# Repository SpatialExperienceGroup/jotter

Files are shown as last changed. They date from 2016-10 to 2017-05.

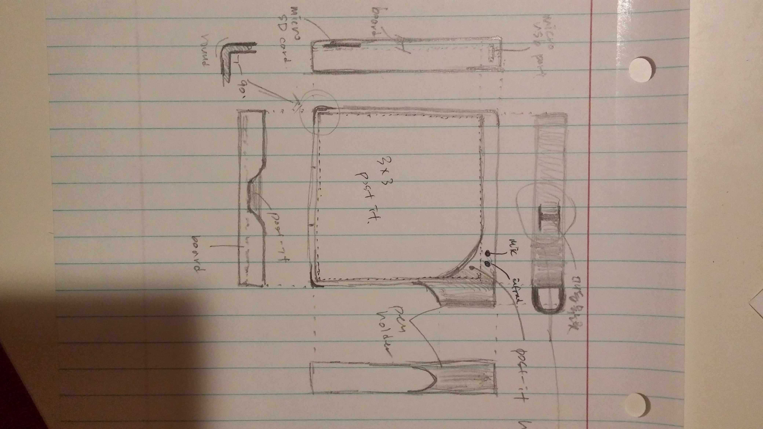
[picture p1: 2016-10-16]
References/20160215_013802_HDR.jpg

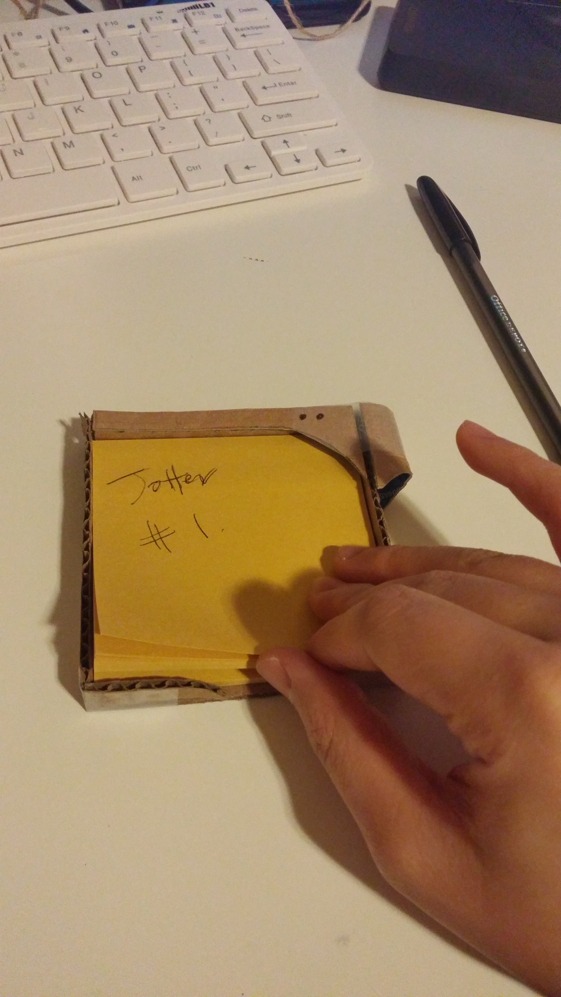
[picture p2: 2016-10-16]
References/20160215_014430_HDR.jpg

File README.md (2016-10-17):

# Jotter

## Requirements
- micro usb port for charging and for updating firmware
- 3.7V from a lipo battery
- lipo charging circuitry through a micro usb port
- bluetooth low energy beacon receiver and transmitter for positioning and ideally multilateration
- MCU to handle bluetooth beacon code
- accurate real time clock
- sd card for storing data; consider storing the unit id number on the sd card
- mems microphone on front for capturing talking of others
- mems microphone on the back for capturing talking of user
- MCU for DFT processing of the audio signals
- IrDA or similar for transmitting and receiving unique IDs to identify users facing users
- MCU to handing IrDA
- accelerometer to identify leaning and sitting
- pressure sensor to identify sitting and standing, usually these are only accurate to within 1 meter, which might not be good enough
- Wi-Fi capability for updating firmware, changing settings, and downloading data
- Any LEDs? charging, Wi-Fi transmission
- Any Buttons? Wi-Fi mode

---------------
## RTC
### DS3231*
- Arduino Library: Rtc by Makuna, Sodaq_DS3231

#### DS3231SN
- has temperature compensated crystal oscillator (may need this for cold temps)
- TCXO:Yes
- Alamrs:2
- $9.97@1, digi-key
- $6.59@100, digi-key
- $2.50@10, aliexpress

---------------
## Coin Cell Retainer/Holder
- Battery:CR2032
- Battery Diameter:20mm

### BU2032

#### BU2032-1-HD-G
- Type:through hole holder
- $0.83@1, digi-key
- $0.69@100, digi-key

#### BU2032SM-HD-G
- Type:surface mount holder
- $0.87@1, digi-key
- $0.76@100, digi-key

#### BK-912
- Type:surface mount retainer
- Notes:easy replacement
- $0.33@1, digi-key
- $0.29@100, digi-key

#### BK-913*
- Type:through hole retainer
- Notes:easy replacement
- $0.35@1, digi-key
- $0.30@100, digi-key

#### BK-888
- Type:through hole retainer
- blocks inner side
- easy replacement
- $0.39@1, digi-key
- $0.33@100, digi-key

---------------
## LDO
- Voltage 3.3V
- needed for running the esp8266 microprocessor and others
- ESP8266 typical
-- Modem-Sleep is 15mA with not much load
-- Wi-Fi Transmission could be up to 170mA, but it is unclear if this is an instantaneous load

### AMS1117-3.3**
- Package:SOT-223
- Current: 1100mA
- Input Voltage: Up to 6V
- Dropout Voltage: 1100mV@800mA
- $1.58@50, aliexpress

### SPX3819M5-L-3-3/TR**
- Package: SOT-23-5
- Current: 500mA
- Input Voltage: Up to 16V
- Dropout Voltage: 340mV@500mA
- $0.72@1, digi-key
- $0.49@100, digi-key

### MCP1700T-3302E/TT
- Package: SOT-23-3
- Current: 250mA
- Input Voltage: Up to 6V
- Dropout Voltage: 178mV@250mA
- $0.37@1, digi-key
- $0.28@100, digi-key

### TC1262-3.3VDBTR
- Package: SOT-223-3
- Current: 500mA
- Input Voltage: Up to 6V
- Dropout Voltage: 350mV@500mA
- $0.51@1, digi-key
- $0.39@100, digi-key

### MIC5528-3.3YMY-TR
- Package: 6-UFDFN (1.2x1.2)
- Current: 525mA
- Input Voltage: 2.5V to 5.5V
- $0.19@1, digi-key
- $0.14@100, digi-key

### NCP161AMX330TBG
- Package: 4-XDFN (1x1)
- Current: 450mA
- Input Voltage: 1.9V to 5.5V
- Dropout Voltage: 150mV@450mA
- $0.46@1, digi-key
- $0.22@100, digi-key

---------------
## LiPo Battery
- 3.7V

### 100mAh
- Weight: 3g
- Size: 11.5mm x 31 x 3.8mm / 0.45" x 1.2" x 0.15"
-   4mA@24hr
-  10mA@10hr
-  $5.95@1, Adafruit
-  $4.76@100, Adafruit

### 150mAh
- Weight: 4.65g
- Size: 19.75mm x 26.02mm x 3.8mm / 0.77" x 1.02" x 0.14"
-   6mA@24hr
-  15mA@10hr
-  $5.95@1, Adafruit
-  $4.76@100, Adafruit

### 350mAh
- Weight: 7.9g
- Size: 36mm x 20mm x 5.6mm / 1.4" x 0.8" x 0.22"
-  14mA@24hr
-  35mA@10hr
-  $6.95@1, Adafruit
-  $5.56@100, Adafruit

### 500mAh**
- Weight: 10.5g
- Size: 29mm x 36mm x 4.75mm / 1.15" x 1.4" x 0.19"
-- Little larger than a US Quarter
-  20mA@24hr
-  50mA@10hr
-  $7.95@1, Adafruit

### 1200mAh*
- Weight: 23g
- Size: 34mm x 62mm x 5mm / 1.3" x 2.4" x 0.2"
-  50mA@24hr
- 120mA@10hr
-  $9.95@1, Adafruit

### 2000mAh
- Weight: 34g
- Size: 60mm x 36mm x 7mm / 2.4" x 1.4" x 0.3"
-  83mA@24hr
- 200mA@10hr
- $12.50@1, Adafruit
- $10.00@100, Adafruit

### 2500mAh
- Weight: 52g
- Size: 2" x 2.55" x 0.30" (51mm x 65mm x 8mm)
- 104mA@24hr
- 250mA@10hr
- $14.95@1, Adafruit
- $11.96@100, Adafruit

---------------
## LiPo Charger

### MCP73831/2**
- Used by Adafruit
- Package: SOT-23-5
- Max Charge Current: 500mA
- Max Input Voltage: 6V
- $0.56@1, digi-key
- $0.42@100, digi-key

### MAX1555EZK+T
- Package: SOT-23-5
- Max Charge Current: 340mA
- Max Input Voltage: 7V
- $2.03@1, digi-key
- $1.34@100, digi-key

---------------
## MCU - Core

### ATSAMD11
- USB: Yes
- VCC: 1.62V - 3.63V
- Current Consumption Idle: 1.8mA
- Current Consumption While: 3mA
- Current Consumption CoreMark: 4mA
- Program Memory: 16KB
- CPU Frequency: 48MHz

#### ATSAMD11C
- SERCOM: 2

##### ATSAMD11C14A
- Package: 14-SOIC
- $2.32@1, digi-key
- $1.69@100, digi-key

#### ATSAMD11D
- SERCOM: 3

##### ATSAMD11D14A

###### ATSAMD11D14A-SSUT**
- Package: 20-SOIC
- $2.54@1, digi-key
- $1.85@100, digi-key

###### ATSAMD11D14A-MUT*
- Package: 24-QFN (4x4)
- $2.65@1, digi-key
- $1.93@100, digi-key

### ATSAMD21
- USB: Yes
- VCC: 1.62V - 3.63V
- Current Consumption Idle: 2.2mA
- Current Consumption While: 4mA
- Current Consumption CoreMark: 7mA
- Program Memory: 32/64/128/256KB
- CPU Frequency: 48MHz
- I2S: Yes

#### ATSAMD21E
- SERCOM:4
- ADC:10

##### ATSAMD21E18A
- Program Memory: 256KB

###### ATSAMD21E18A-MUT
- Package:32-VFQFN
- $5.30@1, digi-key
- $3.88@100, digi-key

###### ATSAMD21E15B-AUT
- Package:32-TQFP (7x7)
- $3.16@1, digi-key
- $2.32@100, digi-key

#### ATSAMD21G
- SERCOM:6
- ADC:14

#### ATSAMD21J
- SERCOM:6
- ADC:20

### LPGA
- Custom Reprogrammable Circuit Design

#### ICE40LP384-SG32
- Package: 32-QFN
- LABS/CLBs: 48
- Logic Elements: 384
- Dev Kit http://www.latticestore.com/searchresults/tabid/463/searchid/1/searchvalue/ice40hx1k-blink-evn/default.aspx
- $1.67@1, digi-key
- $1.38@100, digi-key

---------------
## MCU - IrDA, Bluetooth

### ATtiny85
- GCC Architecture: avr25
- Program Memory: 8KB
- TWI: 0
- SPI: 0
- USART: 0
- ADC: 4x10b

#### ATTINY85-20SU
- Package: 8-SOIC
- CPU Frequency: 20MHz
- $2.24@1, digi-key
- $1.63@100, digi-key

#### ATTINY85-20MUR
- Package: 20-QFN (4x4)
- CPU Frequency: 20MHz
- $2.08@1, digi-key
- $1.51@100, digi-key

### ATtiny841
- Program Memory: 8KB
- GCC Architecture: avr25
- CPU Frequency: 16MHz
- TWI: 1 Slave
- SPI: 1
- USART: 2

#### ATTINY841-SSUR**
- Package: 14-SOIC
- $2.11@1, digi-key
- $1.53@100, digi-key

#### ATTINY841-MUR*
- Package: 20-QFN (4x4)
- $2.16@1, digi-key
- $1.56@100, digi-key

#### ATTINY841-MMHR
- Package: 20-VQFN (3x3)
- $2.32@1, digi-key
- $1.68@100, digi-key

### ATtiny88
- Program Memory: 8KB
- GCC Architecture: avr25
- CPU Frequency: 12MHz
- TWI: 1
- SPI: 1
- USART: 0

#### ATTINY88-MU
- Package: 32-VQFN (5x5)
- $1.82@1, digi-key
- $1.32@100, digi-key

#### ATTINY88-AU
- Package: 32-TQFP (7x7)
- $1.96@1, digi-key
- $1.42@100, digi-key

### ATtiny40
- Program Memory: 4KB
- GCC Architecture: avrtiny10
- CPU Frequency: 12MHz
- TWI: 1 Slave
- SPI: 1
- USART: 0

#### ATTINY40-MMHR
- Package: 20-VQFN (3x3)
- $1.49@1, digi-key
- $1.09@100, digi-key

#### ATTINY40-XUR
- Package: 20-TSSOP
- $2.20@1, digi-key
- $1.60@100, digi-key

#### ATTINY40-SUR
- Package: 20-SOIC
- $2.14@1, digi-key
- $1.55@100, digi-key

### ATtiny828
- Program Memory: 8KB
- GCC Architecture: avr25
- CPU Frequency: 20MHz
- TWI: 1 Slave
- SPI: 1
- USART: 1

#### ATTINY828-AUR
- Package: 32-TQFP (7x7)
- $2.45@1, digi-key
- $1.78@100, digi-key

#### ATTINY828-MUR
- Package: 32-VQFN (5x5)
- $2.67@1, digi-key
- $1.94@100, digi-key

---------------
## MEMS Microphones
- I2S digital input type
- Sensitivity: http://www.analog.com/en/analog-dialogue/articles/understanding-microphone-sensitivity.html
-- In near-field applications, such as cell phones, where the microphone is close to the sound source, a microphone with higher sensitivity is more likely to reach the maximum acoustic input, clip, and cause distortion. On the other hand, a higher sensitivity may be desirable in far-field applications, such as conference phones and security cameras, where the sound is attenuated as the distance from the source to the microphone increases.
-- Normal Conversation at 1m is around 63dB SPL

### SPH0645LM4H-B*
- Port: Bottom
- Frequency Range: 20Hz to 20kHz
- Sensitivity: -26dB ±3dB @ 94dB SPL
- SNR: 65dB(A)
- Supply Volgage: 1.62V to 1.8V to 3.6V
- Supply Current: 0.6mA
- Precision: 18-bit (6 additional bits are zeros, making 24-bit total)
- $3.06@1, digi-key
- $2.29@1, mouser
- $1.90@100, digi-key
- $1.51@100, mouser

### ICS-43432
- Port: Bottom
- Frequency Range: 50Hz to 20kHz
- Sensitivity: -26dB ±1dB @ 94dB SPL
- SNR: 65dB(A)
- Supply Volgage: 1.62V to 1.8V to 3.6V
- Supply Current: 1.5mA
- Precision: 24-bit
- $3.18@1, digi-key
- $2.15@100, digi-key
- example circuit: https://www.tindie.com/products/onehorse/ics43432-i2s-digital-microphone/
- Library: https://github.com/nodae/teensy_i2s_experimental

### INMP441ACEZ-R7
- Port: Bottom
- Frequency Range: 60Hz to 15kHz
- Sensitivity: -26dB ±3dB @ 94dB SPL
- SNR: 61dB(A)
- Supply Volgage: 1.62V to 1.8V to 3.6V
- Supply Current: 1.6mA
- Precision: 24-bit
- $4.35@1, digi-key
- $3.14@100, digi-key

### SPU0414HR5H
- Output Type: Analog
- Port: Top
- Frequency Range: 100Hz to 10kHz
- Sensitivity: -22dB ±3dB @ 94dB SPL
- SNR: 59dB(A)
- Supply Volgage: 1.5V to 3.6V
- Supply Current: 0.22mA
- $2.01@1, digi-key
- $1.10@100, digi-key
- $1.87@1, mouser
- $1.03@100, mouser

### SPW2430HR5H-B
- Output Type: Analog
- Port: Top
- Frequency Range: 100Hz to 10kHz
- Sensitivity: -42dB ±3dB @ 94dB SPL (not good)
- SNR: 59dB(A)
- Supply Volgage: 1.5V to 3.6V
- Supply Current: 0.11mA
- $1.11@1, digi-key
- $0.60@100, digi-key
- $1.04@1, mouser
- $0.59@100, mouser

## MCU - DFT Audio Signal Processor
- Interface: I2S

### ESP8266*
- Wi-Fi:Yes
- Allows us to have a Wi-Fi interface for setting the time and other settings.
- VCC:3.3V
- Runs on 3.3V, so should have an LDO or similar to bring down the 5V supply.
- pin mapping: http://www.esp8266.com/wiki/doku.php?id=esp8266_gpio_pin_allocations
- Has I2S inputs for digital audio of Left and Right microphones
- Peak Current Consumption on Startup: 320mA (use 470uF SMD)
- Current Consumption Idle: 15mA
- Current Consumption Wi-Fi Receive: 70mA
- Current Consumption Wi-Fi Transmit: <170mA
- I2S Forum: http://www.esp8266.com/viewtopic.php?f=13&t=7404
- I2S Example Code: https://github.com/cnlohr/esp8266duplexi2s
- DFT Example Code: https://github.com/cnlohr/channel3

### ATSAMD21

#### ATSAMD21E18A-MUT
- Package:32-VFQFN
- $5.30@1, digi-key
- $3.88@100, digi-key

#### ATSAMD21E15B-AUT
- Package:32-TQFP (7x7)
- $3.16@1, digi-key
- $2.32@100, digi-key

---------------
## IrDA Transciever
- http://www.societyofrobots.com/electronics_irda_tutorial.shtml
- Modulation Frequency: 38KHz
- most single packages are expensive, so we split into two parts
- may need to offload processing to small chip like Attiny85

### IrDA Sensor Pair

### IrDA Processor
- Encoder/Decoder

#### ATtiny MCU

#### MCP2155

#### MCP2122

### IrDA Receiver

#### VS1838B

#### TSOP38238

#### TSOP4038

#### TSOP4838

#### HS0038B

#### TSOP58238

#### TSOP6238TR

#### TSMP77000TT
- Distance: 5m
- Voltage Supply: 2.5V to 5.5V
- $1.66@1, digi-key
- $1.21@100, digi-key

### IrDA Transmitter
- Can be controlled with a 555 timer or an MCU

#### ATtiny MCU

#### NE555
- Supply Voltage: Typically 5V operation
- Max Frequency: 1MHz

#### TLC555
- Supply Voltage: 2V-15V
- Temperature Range: 0C to +70C
- Package: 8-SOIC
- Max Frequency: 2.1MHz
- $0.72@1, digi-key
- $0.48@100, digi-key

#### ICM7555
- Supply Voltage: 2V-18V
- Drop in replacement for NE555
- Max Frequency: 1MHz

##### ICM7555CBAZ
- Package: 8-SOIC
- Temperature Range: 0C to +70C
- $0.73@1, digi-key
- $0.50@100, digi-key

##### ICM7555IBAZ
- Package: 8-SOIC
- Temperature Range: -25C to +85C
- $0.73@1, digi-key
- $0.50@100, digi-key

---------------
## IMU
- need to detect sitting vs standing
- may include accelerometer, gyro, barometer, and perhaps magnetometer; why not

### MPU9250
- DoF:9

---------------
## Environmental Sensor

### BMP280

---------------
## Bluetooth Module for Beacon

### nRF24L01+*
- Chipset: nRF24L01
- FCC Certified: No

### MDBT40P**
- Chipset:nrf51822
- FCC Certified: Yes, SH6MDBT40

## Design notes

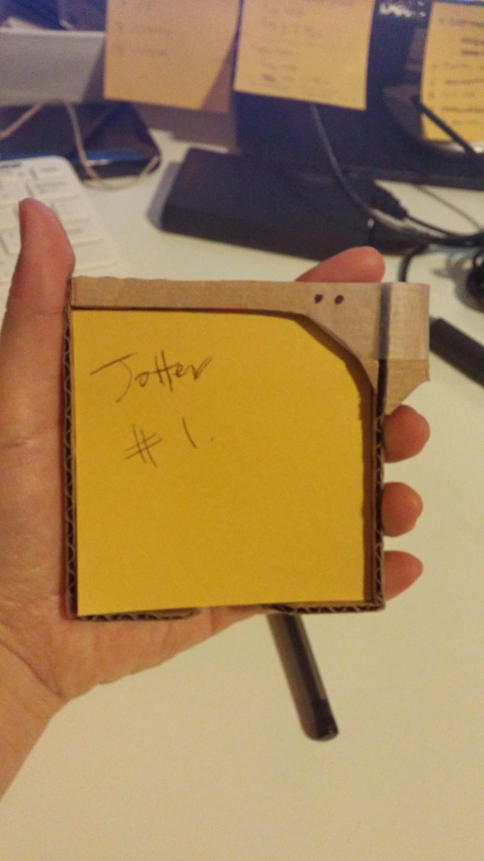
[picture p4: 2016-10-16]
References/20160215_014537_HDR.jpg

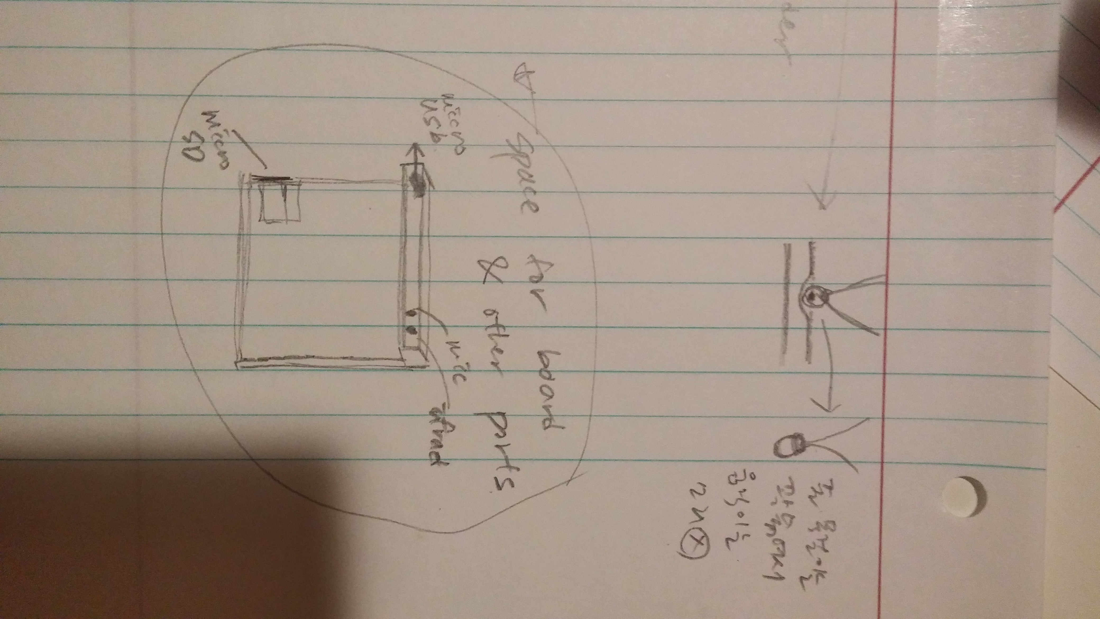
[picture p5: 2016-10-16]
References/20160215_013808_HDR.jpg

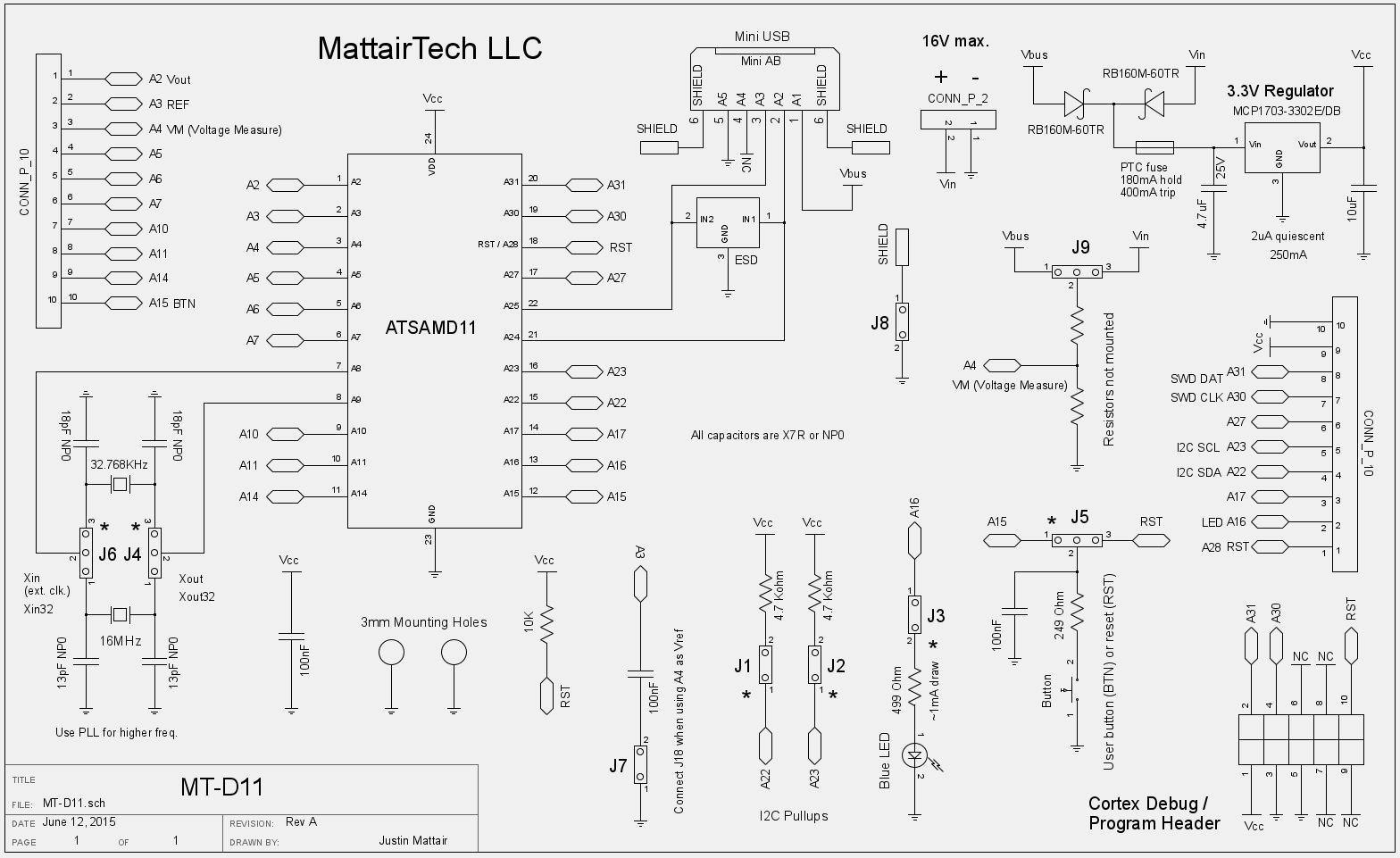
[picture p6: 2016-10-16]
References/research/mt-d11.png

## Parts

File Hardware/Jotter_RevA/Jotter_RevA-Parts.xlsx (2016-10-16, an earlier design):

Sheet: Jotter_Rev1
Section | part | specs | footprint | qty | unit cost | unit 100 | supplier | qty10 | part number | hyperlink | subtotal | subtotal10 | subtotal100 | notes
https://learn.adafruit.com/assets/29013 |  |  |  |  |  |  |  |  |  |  | $140.95 | $266.87 | $22.17
Bluetooth
 | HM11 |  | HM11 | 1 | 6.1 | 5.53 | FastTech | 0 | HM-11 Bluetooth | https://www.fasttech.com/products/0/10008268/1740900-hm-11-bluetooth-v4-0-transceiver-ble-module | 6.1 | 0 | 553
SD Card
 | MicroSD Socket | Push/Pull |  | 1 | 1.88 | 1.4608 | Digi-Key | 10 | HR1941CT-ND | http://www.digikey.com/product-detail/en/DM3D-SF/HR1941CT-ND/1786515 | 1.88 | 18.8 | 146.08
Power
 | USB Plug | USB-A, SMD |  | 1 | 0.89 | 0.6732 | Digi-Key | 0 | 609-4413-ND | http://www.digikey.com/product-detail/en/87583-2010BLF/609-4413-ND/2665595 | 0.89 | 0 | 0.599148
 | MicroUSB Socket |  |  | 0 | 0.46 | 0.3032 | Digi-Key | 10 | 609-4618-1-ND | http://www.digikey.com/product-detail/en/10118194-0001LF/609-4618-1-ND/2785382 | 0 | 4.6 | 0
 | Lithium Ion Charger | MCP7833 |  | 0 | 0.85 | 0.65 | Digi-Key | 0 | MCP73833-AMI/UN-ND | http://www.digikey.com/product-detail/en/MCP73833-AMI%2FUN/MCP73833-AMI%2FUN-ND/1223157 | 0 | 0 | 0
 | Lithium Ion Charger | MCP73831 | SOT23-5 | 1 | 0.56 | 0.42 | Digi-Key | 10 | MCP73831T-2ACI/OTCT-ND | http://www.digikey.com/product-detail/en/MCP73831T-2ACI%2FOT/MCP73831T-2ACI%2FOTCT-ND/1979802 | 0.56 | 5.6 | 42
 | Voltage Regulator 3.3V | SPX3819 | SOT23-5 | 1 | 0.72 | 0.4868 | Digi-Key | 10 | 1016-1873-1-ND | http://www.digikey.com/product-detail/en/SPX3819M5-L-3-3%2FTR/1016-1873-1-ND/3586590 | 0.72 | 7.2 | 48.68
 | Lithium Ion Battery | 3.7V, 1200mAh |  | 1 | 9.95 | 7.96 | Adafruit | 0 | 258 | https://www.adafruit.com/products/258 | 9.95 | 0 | 796
 | JST Plug | 2-pin |  | 1 | 0.58 | 0.4194 | Digi-Key | 10 | 455-1749-1-ND | http://www.digikey.com/product-detail/en/S2B-PH-SM4-TB(LF)(SN)/455-1749-1-ND/926846 | 0.58 | 5.8 | 41.94
 | Schottkey Diode | 20V 1A (MBR120) | SOD123 | 1 | 0.45 | 0.1911 | Digi-Key | 10 | MBRX120TPMSCT-ND | http://www.digikey.com/product-detail/en/MBRX120-TP/MBRX120TPMSCT-ND/717378 | 0.45 | 4.5 | 19.11
 | 1uF cap |  | 0805 | 3 | 0.12 | 0.0407 | Digi-Key | 30 | 399-1284-1-ND | http://www.digikey.com/product-detail/en/C0805C105K4RACTU/399-1284-1-ND/416060 | 0.36 | 3.6 | 12.21
 | 10uF cap |  | 0805 | 4 | 0.21 | 0.0714 | Digi-Key | 40 | 399-4925-1-ND | http://www.digikey.com/product-detail/en/C0805C106K8PACTU/399-4925-1-ND/1090920 | 0.84 | 8.4 | 28.56
 | 100K |  | 0805 | 3 | 0.1 | 0.0162 | Digi-Key | 30 | P100KCCT-ND | http://www.digikey.com/product-detail/en/ERJ-6ENF1003V/P100KCCT-ND/119551 | 0.3 | 3 | 4.86
 | 10K | 10K = 100mA charge | 0805 | 1 | 0.1 | 0.011 | Digi-Key | 10 | P10KACT-ND | http://www.digikey.com/product-detail/en/ERJ-6GEYJ103V/P10KACT-ND/43118 | 0.1 | 1 | 1.1
 | 1K |  | 0805 | 2 | 0.1 | 0.0162 | Digi-Key | 20 | P1.00KCCT-ND | http://www.digikey.com/product-detail/en/ERJ-6ENF1001V/P1.00KCCT-ND/118957 | 0.2 | 2 | 3.24
 | 2.2K |  | 0805 | 1 | 0.1 | 0.0162 | Digi-Key | 10 | P2.20KCCT-ND | http://www.digikey.com/product-detail/en/ERJ-6ENF2201V/P2.20KCCT-ND/1746832 | 0.1 | 1 | 1.62
 | Red LED |  | 0805 | 1 | 0.28 | 0.119 | Digi-Key | 10 | 475-1278-1-ND | http://www.digikey.com/product-detail/en/LS%20R976-NR-1/475-1278-1-ND/1642798 | 0.28 | 2.8 | 11.9
 | Green LED |  | 0805 | 1 | 0.26 | 0.1131 | Digi-Key | 10 | 475-1410-1-ND | http://www.digikey.com/product-detail/en/LG%20R971-KN-1/475-1410-1-ND/1802598 | 0.26 | 2.6 | 11.31
 | Orange LED |  | 0805 | 1 | 0.28 | 0.119 | Digi-Key | 10 | 475-2560-1-ND | http://www.digikey.com/product-detail/en/LY%20R976-PS-36/475-2560-1-ND/1802687 | 0.28 | 2.8 | 11.9
 | Switch/Button for reset | SPST_TACT_KMR2 | Gull Wing | 1 | 0.51 | 0.4017 | Digi-Key | 10 | 401-1427-1-ND | http://www.digikey.com/product-detail/en/KMR221GLFS/401-1427-1-ND/550466 | 0.51 | 5.1 | 40.17
MCU
 | Cortex M0+ | ATSAMD21G18 (256KB+USB) | 48-TQFP | 0 | 6.22 | 4.5557 | Digi-Key | 0 | ATSAMD21G18A-AFTCT-ND | http://www.digikey.com/product-detail/en/ATSAMD21G18A-AFT/ATSAMD21G18A-AFTCT-ND/5119076 | 0 | 0 | 0
 | Cortex M0+ | ATSAMD09C13 (8KB) | 14-SOIC | 0 | 1.15 | 0.8029 | Digi-Key | 0 | ATSAMD09C13A-SSUTCT-ND | http://www.digikey.com/product-detail/en/ATSAMD09C13A-SSUT/ATSAMD09C13A-SSUTCT-ND/5404072 | 0 | 0 | 0
 | Cortex M0+ | ATSAMD11C14A-SSUT | 14-SOIC | 1 | 2.29 | 1.6662 | Digi-Key | 10 | ATSAMD11C14A-SSUTCT-ND | http://www.digikey.com/product-detail/en/ATSAMD11C14A-SSUT/ATSAMD11C14A-SSUTCT-ND/5226479 | 2.29 | 22.9 | 166.62 | includes USB
 | Cortex M0+ | ATSAMD11D14A-SSUT | 20-SOIC | 0 | 2.54 | 1.8437 | Digi-Key | 1 | ATSAMD11D14A-SSUTCT-ND | http://www.digikey.com/product-detail/en/ATSAMD11D14A-SSUT/ATSAMD11D14A-SSUTCT-ND/5226483 | 0 | 2.54 | 0
 | Crystal | 32.768 KHz |  | 1 | 0.38 | 0.252 | Digi-Key | 10 | 535-9166-1-ND | http://www.digikey.com/product-detail/en/ABS25-32.768KHZ-T/535-9166-1-ND/675683 | 0.38 | 3.8 | 25.2
 | 22pF Cap |  | 0805 | 2 | 0.1 | 0.022 | Digi-Key | 20 | 399-1113-1-ND | http://www.digikey.com/product-detail/en/C0805C220J5GACTU/399-1113-1-ND/411388 | 0.2 | 2 | 4.4
RTC
 | Real Time Clock |  | 8-SOIC | 1 | 0.89 | 0.598 | Digi-Key | 10 | 568-6650-1-ND | http://www.digikey.com/product-detail/en/PCF8563T%2F5,518/568-6650-1-ND/2617089 | 0.89 | 8.9 | 59.8
 | Coin Cell Battery | CR2032, 3V, 20mm |  | 1 | 0.28 | 0.2266 | Digi-Key | 10 | P189-ND | http://www.digikey.com/product-detail/en/CR2032/P189-ND/31939 | 0.28 | 2.8 | 22.66
 | Coin Cell Holder | 2032, SMD, 20mm |  | 1 | 0.34 | 0.29 | Digi-Key | 10 | BK-912-ND | http://www.digikey.com/product-detail/en/BK-912/BK-912-ND/2647825 | 0.34 | 3.4 | 29
IR LEDs
 | IR LED | 940nm | Gull Wing | 0 | 0.88 | 0.4813 | Digi-Key | 0 | VSMB2020X01CT-ND | http://www.digikey.com/product-detail/en/VSMB2020X01/VSMB2020X01CT-ND/2713173 | 0 | 0 | 0
 | IR Diode | 940nm | Gull Wing | 0 | 0.99 | 0.5445 | Digi-Key | 0 | VEMD2020X01CT-ND | http://www.digikey.com/product-detail/en/VEMD2020X01/VEMD2020X01CT-ND/2713169 | 0 | 0 | 0
 | IR Sensor | 5m | 4 | 1 | 1.79 | 1.2495 | Digi-Key | 10 | TSMP77000TCT-ND | http://www.digikey.com/product-detail/en/TSMP77000TT/TSMP77000TCT-ND/4696172 | 1.79 | 17.9 | 124.95
 | 100 |  | 0805 | 1 | 0.1 | 0.0162 | Digi-Key | 10 | P100CCT-ND | http://www.digikey.com/product-detail/en/ERJ-6ENF1000V/P100CCT-ND/118668 | 0.1 | 1 | 1.62
 | 4.7K |  | 0805 | 1 | 0.1 | 0.011 | Digi-Key | 10 | P4.7KACT-ND | http://www.digikey.com/product-detail/en/ERJ-6GEYJ472V/P4.7KACT-ND/82468 | 0.1 | 1 | 1.1
 | 4.7uF |  | 0805 | 1 | 0.18 | 0.063 | Digi-Key | 10 | 399-3133-1-ND | http://www.digikey.com/product-detail/en/C0805C475K8PACTU/399-3133-1-ND/551638 | 0.18 | 1.8 | 6.3
Ambient Microphone
 | Electret |  |  | 1 | 1.11 | 0.5979 | Digi-Key | 10 | 423-1394-1-ND | http://www.digikey.com/product-detail/en/SPW2430HR5H-B/423-1394-1-ND/5052772 | 1.11 | 11.1 | 0.663669
Audio Microphone
 | Button
 | Electret
Accelerometer
 | Accelerometer
Programmer/Debugger
 | ATMEL ICE | Full Kit |  | 1 | 92.94 |  | Digi-Key | 1 | ATATMEL-ICE-ND | http://www.digikey.com/product-detail/en/ATATMEL-ICE/ATATMEL-ICE-ND/4753379 | 92.94 | 92.94 | 0
 | ATMEL ICE | Basic |  | 0 | 53.58 |  | Digi-Key | 0 | ATATMEL-ICE-BASIC-ND | http://www.digikey.com/product-detail/en/ATATMEL-ICE-BASIC/ATATMEL-ICE-BASIC-ND/4753381 | 0 | 0 | 0 | 50-mil 10-pin mini squid cable with 10 x 100-mil sockets
 | SOIC Clip | 20 pin |  | 1 | 15.99 |  | Digi-Key | 1 | 501-1661-ND | http://www.digikey.com/product-detail/en/5253/501-1661-ND/737207 | 15.99 | 15.99 | 0

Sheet: Sheet1
SAMD11C | SAMD11D | I/O Pin | MATTAIRTECH |  |  |  | ADC | MY11C | MY11D20 | MY11D24 | SERCOM | SERCOMALT
13 | 18 | PA02 | 2 | ADC0 |  | DAC | 0 | D/DAC | D/DAC | D/DAC
 | 19 | PA03 | 3 | ADC1 |  | AREF | 1 |  | D | D
14 | 20 | PA04 | 4 | ADC2 | INT4 |  | 2 | D|MISO | MISO | MISO | M0-2 | M0-0
1 | 1 | PA05 | 5 | ADC3 | INT5 |  | 3 | D|SS | SS | SS | M0-3 | M0-1
 | 2 | PA06 | 6 | ADC4 |  |  | 4 |  | MOSI | MOSI | M0-0 | M0-2
 | 3 | PA07 | 7 | ADC5 |  |  | 5 |  | SCK | SCK | M0-1 | M0-3
2 | 4 | PA08 |  | XIN |  |  |  | XIN | XIN | XIN | M1-2 | M0-2
3 | 5 | PA09 |  | XOUT |  |  |  | XOUT | XOUT | XOUT | M1-3 | M0-3
 |  | PA10 | 10 | ADC8 | INT2 | MOSI | 8 |  |  |  | M0-2 | M2-2
 |  | PA11 | 11 | ADC9 |  | SCK | 9 |  |  |  | M0-3 | M2-3
4 | 6 | PA14 | 14 | ADC6 | INTNMI | MISO | 6 | SDA|MOSI | D | D | M0-0 | M2-0
5 | 7 | PA15 | 15 | ADC7 | INT1 | SS/BTN | 7 | SCL|SCK | D | D | M0-1 | M2-1
 | 8 | PA16 | 16 |  | INT0 | LED |  |  | D | D | M1-2 | M2-2
 |  | PA17 | 17 |  |  |  |  |  |  |  | M1-3 | M2-3
 | 9 | PA22 | 22 |  | INT6 | SDA |  |  | SDA | SDA | M1-0 | M2-0
 | 10 | PA23 | 23 |  |  | SCL |  |  | SCL | SCL | M1-1 | M2-1
 |  | PA27 | 27 |  | INT7
6 | 11 | PA28 |  |  |  | RESET |  | RESET | RESET | RESET
7 | 12 | PA30 | 30 |  |  | TX/SWDCLK |  | TX/SWDCLK | TX/SWDCLK | TX/SWDCLK | M1-0 | M1-2
8 | 13 | PA31 | 31 |  | INT3 | RX/SWDIO |  | RX/SWDIO | RX/SWDIO | RX/SWDIO | M1-1 | M1-3
9 | 14 | PA24 |  |  |  |  | USB/DM | USB/DM | USB/DM | USB/DM | M1-2 | M2-2
10 | 15 | PA25 |  |  |  |  | USB/DP | USB/DP | USB/DP | USB/DP | M1-3 | M2-3

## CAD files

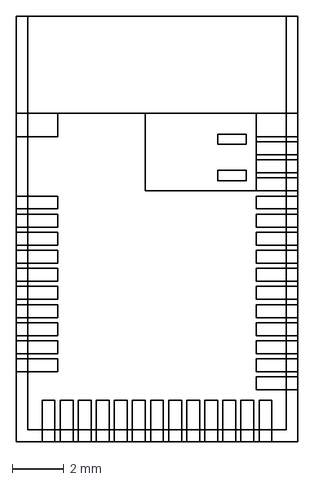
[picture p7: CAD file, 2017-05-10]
References/parts/MDBT42Q.dxf
10.9 x 16.5 mm

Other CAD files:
References/parts/MDBT42Q.dwg

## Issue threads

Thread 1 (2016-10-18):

Create MEMS Microphone Breakout Board

strontium5, 2016-10-18:
MEMS are too small to mill in house, so we need a breakout board to bridge to in house development boards.

Closed 2016-10-18.

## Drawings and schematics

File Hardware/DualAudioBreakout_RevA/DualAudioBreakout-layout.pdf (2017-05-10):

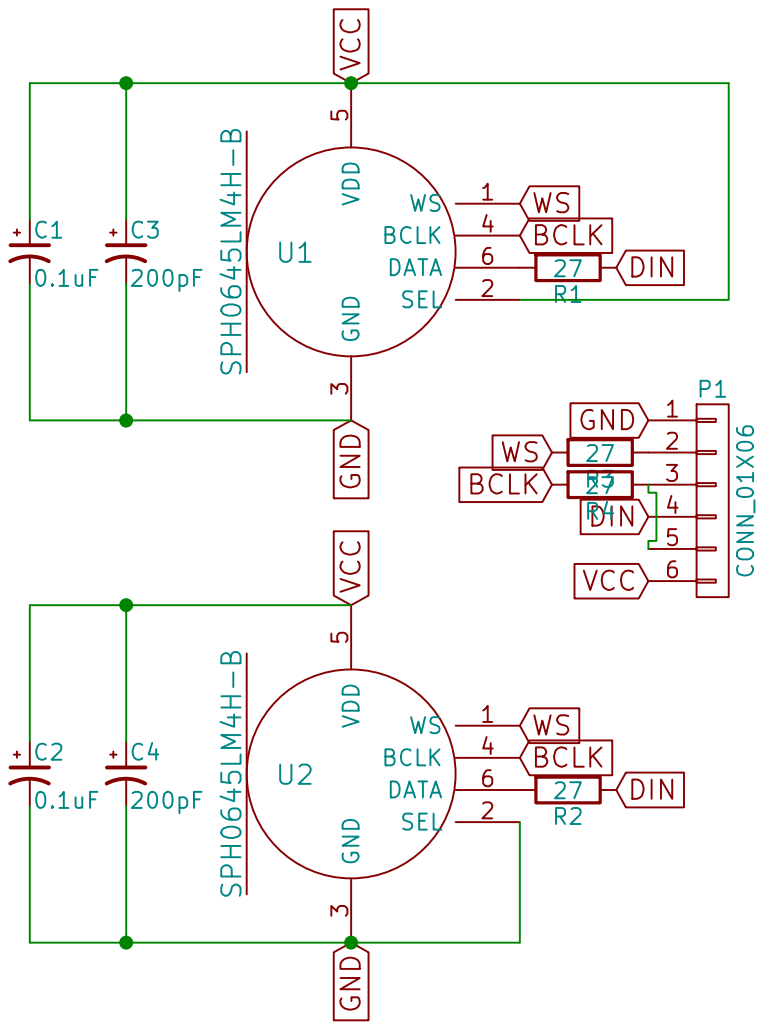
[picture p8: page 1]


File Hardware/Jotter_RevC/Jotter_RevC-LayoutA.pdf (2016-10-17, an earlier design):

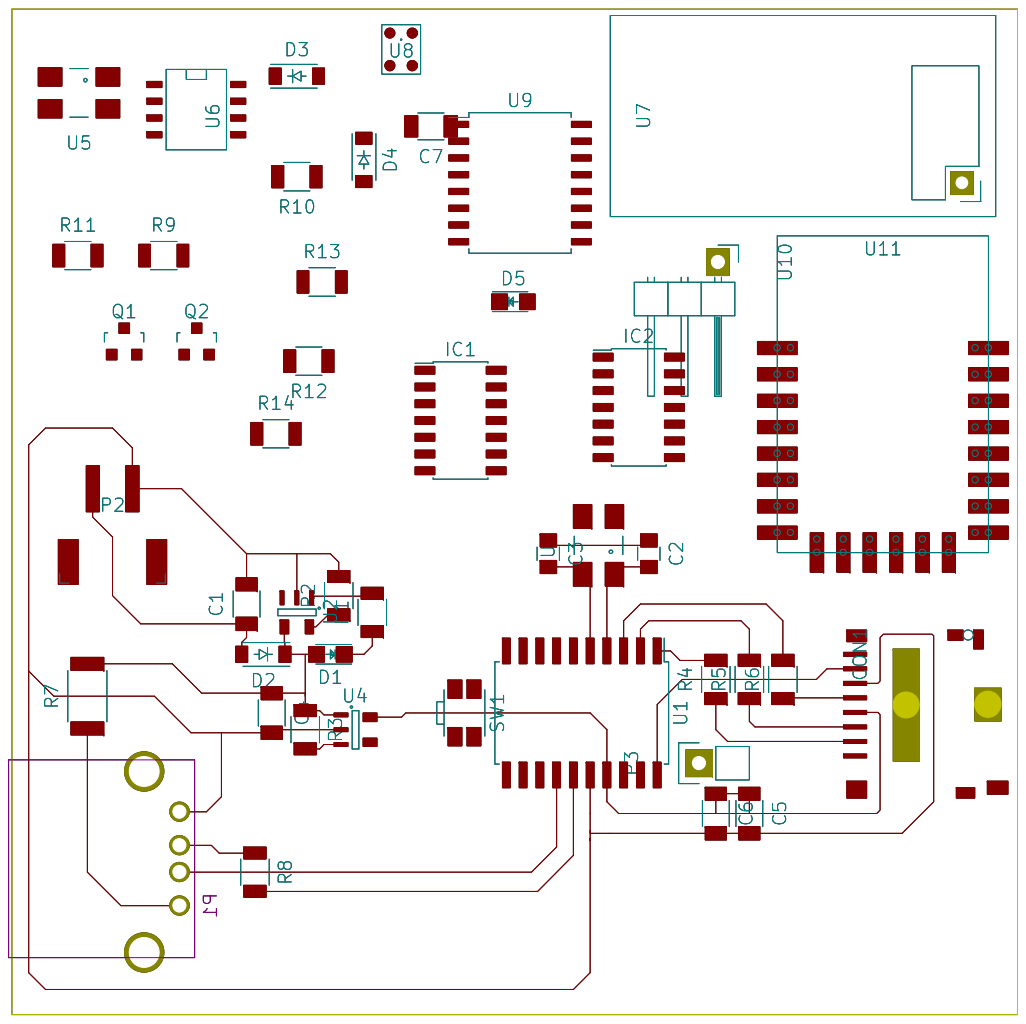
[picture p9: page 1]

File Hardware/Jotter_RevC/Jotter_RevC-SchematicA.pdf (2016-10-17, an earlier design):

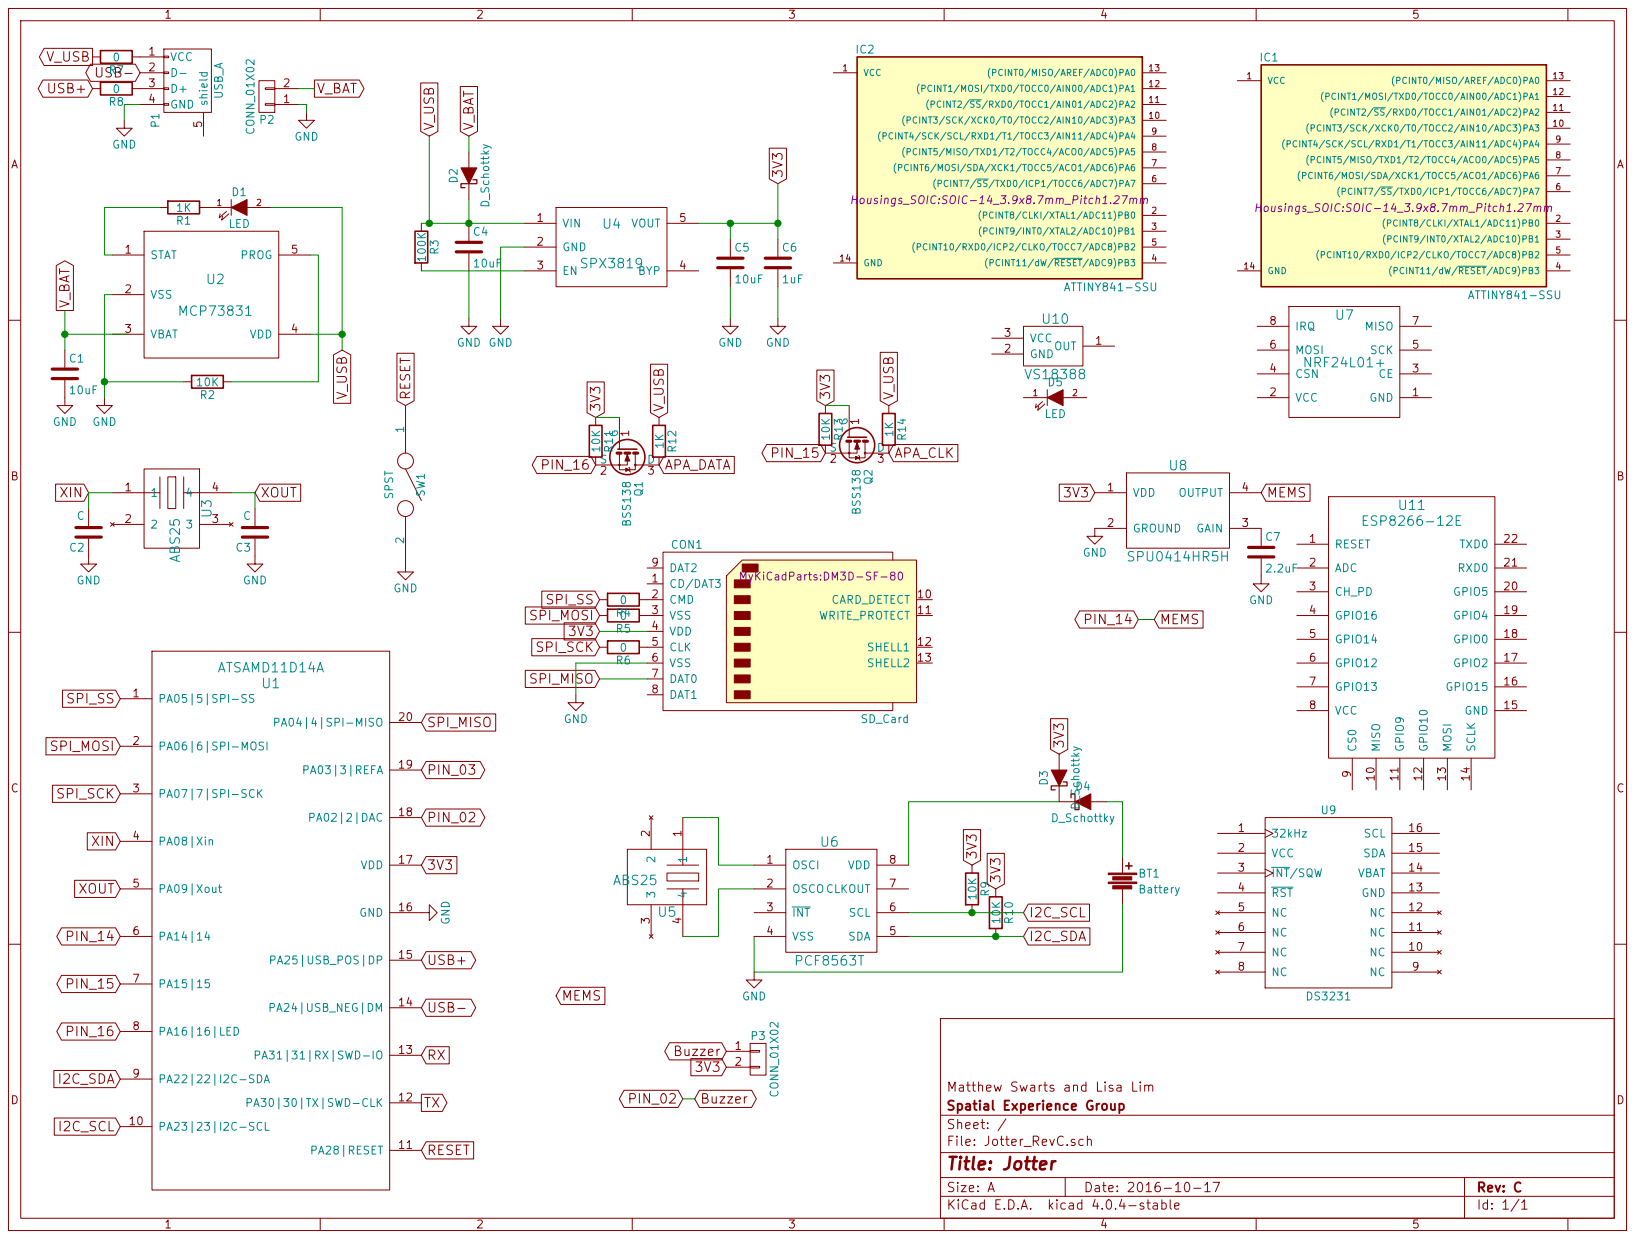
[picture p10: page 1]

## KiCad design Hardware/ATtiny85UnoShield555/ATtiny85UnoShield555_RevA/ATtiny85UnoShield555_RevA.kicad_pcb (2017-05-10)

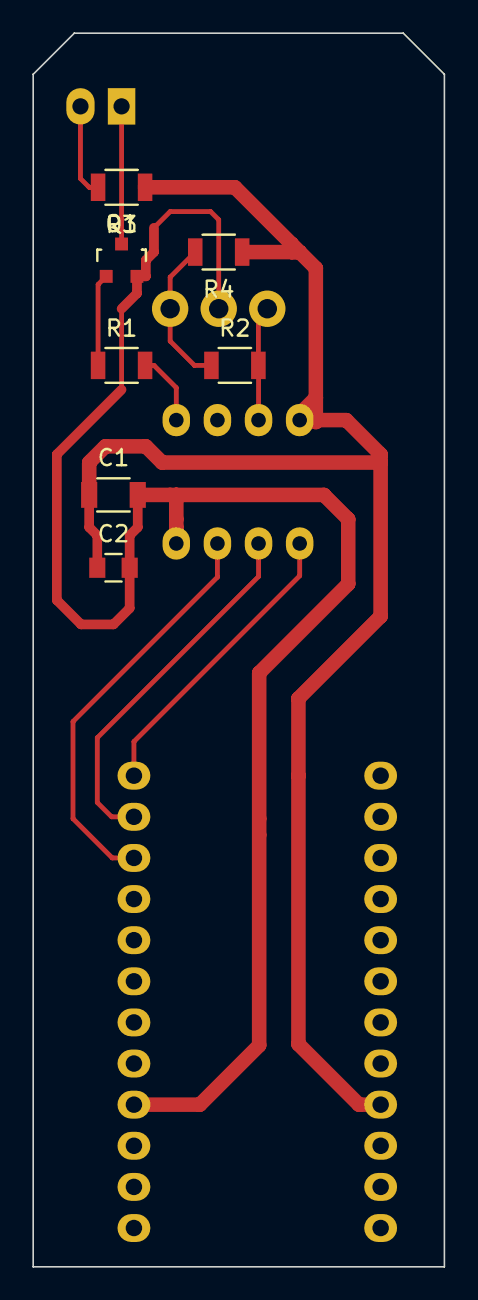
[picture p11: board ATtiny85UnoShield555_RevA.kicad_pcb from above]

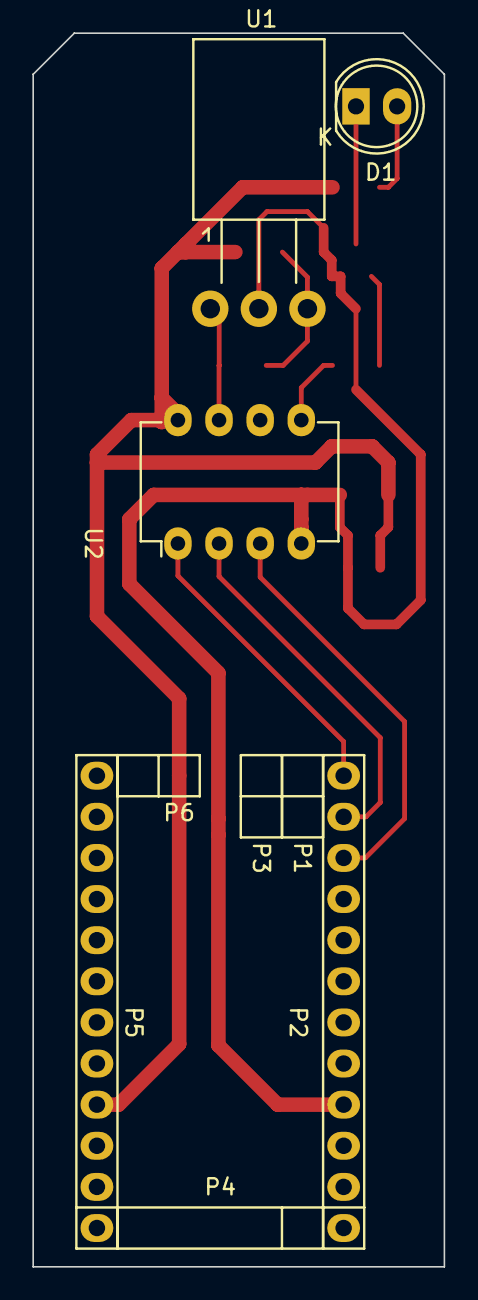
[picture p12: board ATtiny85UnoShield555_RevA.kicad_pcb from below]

Board: 2 copper layers, 25.4 x 76.2 mm, 16 parts (9 on the bottom side), 12 nets.

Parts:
C1: 10uF; C_1206
C2: 0.1uF; C_0805
D1: LED; LED-5MM
P1, P3: ADC; Socket_Strip_Arduino_1x02
P2: Digital; Socket_Strip_Arduino_1x12
P4: COM; Socket_Strip_Arduino_1x05
P5: Analog; Socket_Strip_Arduino_1x12
P6: PWR; Socket_Strip_Arduino_1x02
Q1: BSS138; SOT-23
R1: 1K; R_1206
R2: 10K; R_1206
R3: 10; R_1206
R4: 47; R_1206
U1: TSOP382xx; SOT126_SOT32_Housing_Horizontal
U2: ATTINY85-20PU; DIP-8_W7.62mm

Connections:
/Reset: P2.3, P5.3
FROM_IR_RECEIVER: R2.2, U1.1, U2.7
GND: C1.2, C2.2, P2.4, P5.2, Q1.2, U1.2, U2.4
unnamed: D1.1, Q1.3
unnamed: D1.2, R3.2
unnamed: Q1.1, R1.1
unnamed: R2.1, R4.2, U1.3
TINY_RESET: P2.12, U2.1
TO_IR_TRANSMITTER: R1.2, U2.5
TX_TO_MCU: P2.10, U2.3
TX_TO_TINY: P2.11, U2.2
V33: C1.1, C2.1, P5.4, R3.1, R4.1, U2.8

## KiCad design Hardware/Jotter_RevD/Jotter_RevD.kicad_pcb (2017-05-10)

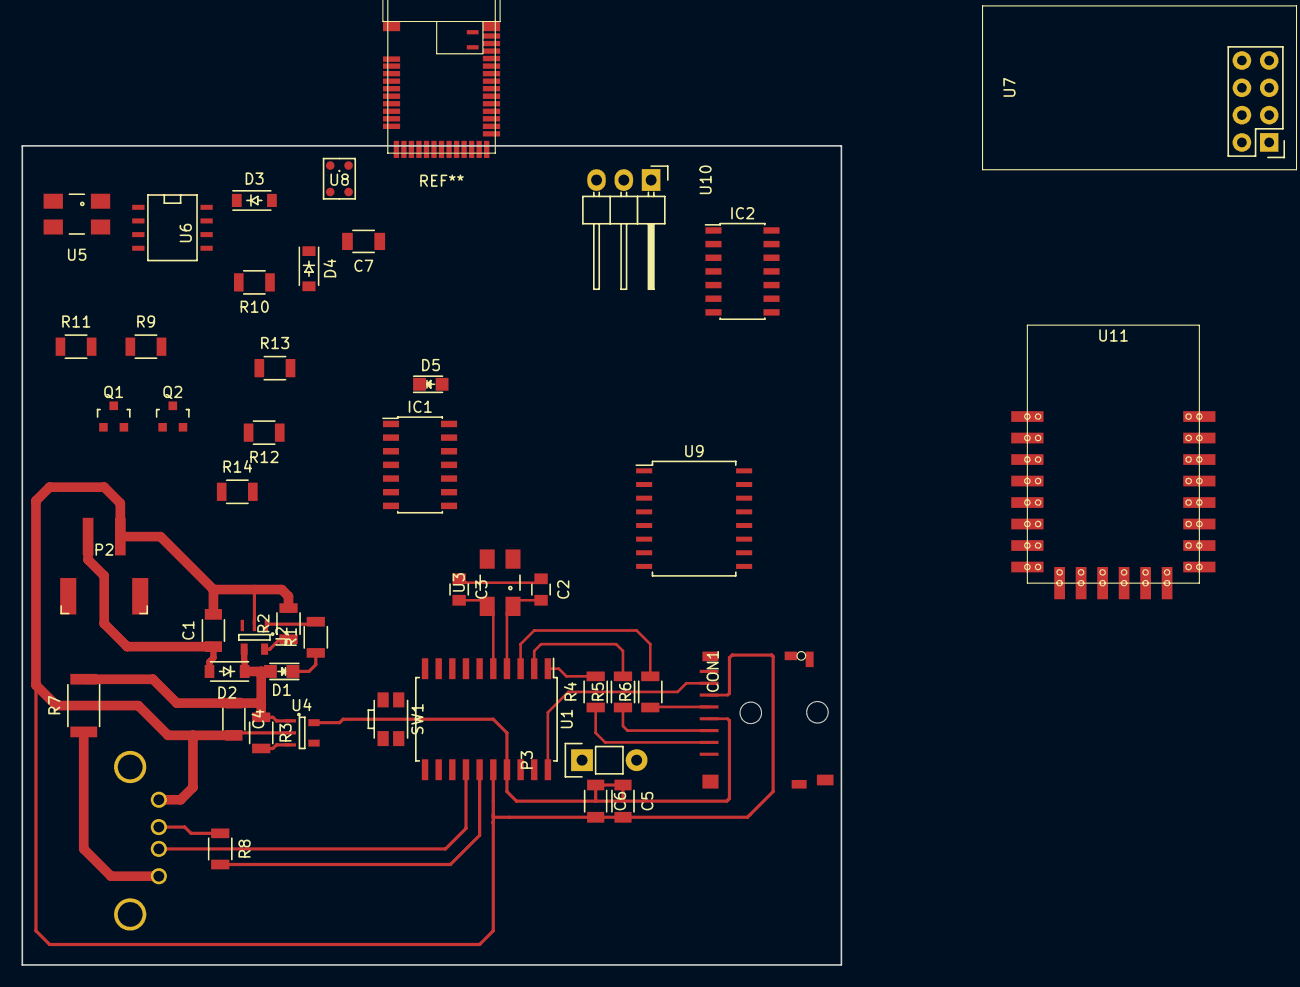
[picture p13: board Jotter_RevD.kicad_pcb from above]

Board: 2 copper layers, 76.2 x 76.2 mm, 46 parts (1 on the bottom side), 34 nets.

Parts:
C1, C4, C5: 10uF; C_1206
C2, C3: C; C_0805
C6: 1uF; C_1206
C7: 2.2uF; C_1206
CON1: SD_Card; DM3D-SF-80
D1, D5: LED; LED-0805
D2, D3, D4: D_Schottky; SOD-123
IC1, IC2: ATTINY841-SSU; SOIC-14_3.9x8.7mm_Pitch1.27mm
P1: USB_A
P2: CONN_01X02; JST-S2B-PH-SM4
P3: CONN_01X02; Pin_Header_Straight_1x02
Q1, Q2: BSS138; SOT-23
R1, R12, R14: 1K; R_1206
R2, R9, R10, R11, R13: 10K; R_1206
R3: 100K; R_1206
R4, R5, R6, R8: 0; R_1206
R7: 0; R_2010
SW1: SPST; SW_SPST_EVQP7A
U1: ATSAMD11D14A; SOIC-20_7.5x12.8mm_Pitch1.27mm
U2: MCP73831; SOT-23-5-80
U3, U5: ABS25; Crystal_SMD_0603_4Pads
U4: SPX3819; SOT-23-5-80
U6: PCF8563T; SO-08-N-80
U7: NRF24L01+
U8: SPU0414HR5H; SPU0414HR5H-SB
U9: DS3231; SOIC-16-W-80
U10: VS18388; Pin_Header_Angled_1x03
U11: ESP8266-12E; ESP8266-12E-80

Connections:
3V3: C5.1, C6.1, CON1.4, D3.2, P3.2, Q1.1, Q2.1, R9.1, R10.1, R11.1, R13.1, U1.17, U4.5, U8.1
APA_CLK: Q2.3, R14.2
APA_DATA: Q1.3, R12.2
Buzzer: P3.1, U1.18
GND: C1.2, C2.1, C3.1, C4.2, C5.2, C6.2, C7.2, CON1.6, P1.4, P2.1, R2.2, SW1.2, U1.16, U2.2, U4.2, U6.4, U8.2
I2C_SCL: R9.2, U1.10, U6.6
I2C_SDA: R10.2, U1.9, U6.5
MEMS: U1.6, U8.4
unnamed: C7.1, U8.3
unnamed: CON1.2, R4.1
unnamed: CON1.3, R5.1
unnamed: CON1.5, R6.1
unnamed: D1.1, R1.1
unnamed: D3.1, D4.1, U6.8
unnamed: P1.1, R7.1
unnamed: P1.3, R8.1
unnamed: R1.2, U2.1
unnamed: R2.1, U2.5
unnamed: R3.2, U4.3
unnamed: U5.1, U6.1
unnamed: U5.4, U6.2
PIN_15: Q2.2, R13.2, U1.7
PIN_16: Q1.2, R11.2, U1.8
RESET: SW1.1, U1.11
SPI_MISO: CON1.7, U1.20
SPI_MOSI: R5.2, U1.2
SPI_SCK: R6.2, U1.3
SPI_SS: R4.2, U1.1
USB+: R8.2, U1.15
USB-: P1.2, U1.14
V_BAT: C1.1, D2.2, P2.2
V_USB: C4.1, D1.2, D2.1, R3.1, R7.2, R12.1, R14.1, U2.4, U4.1
XIN: C2.2, U1.4, U3.1
XOUT: C3.2, U1.5, U3.4

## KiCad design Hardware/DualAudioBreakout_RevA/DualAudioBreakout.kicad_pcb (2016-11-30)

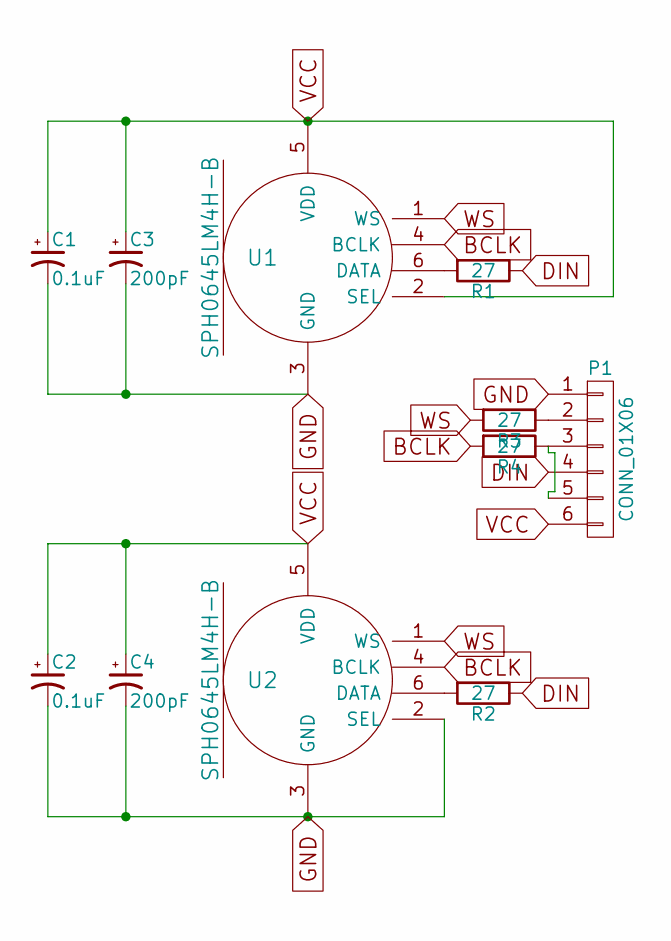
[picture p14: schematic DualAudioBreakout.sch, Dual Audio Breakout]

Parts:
C1, C2: 0.1uF; C_0805
C3, C4: 200pF; C_0805
P1: CONN_01X06; Pin_Header_Straight_1x06
R1, R2, R3, R4: 27; R_0805
U1, U2: SPH0645LM4H-B

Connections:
BCLK: R4.2, U1.4 (BCLK), U2.4 (BCLK)
DIN: P1.4, R1.1, R2.1
GND: C1.2, C2.2, C3.2, C4.2, P1.1, U1.3 (GND), U2.2 (SEL), U2.3 (GND)
unnamed: P1.2, R3.1
unnamed: P1.3, P1.5, R4.1
unnamed: R1.2, U1.6 (DATA)
unnamed: R2.2, U2.6 (DATA)
VCC: C1.1, C2.1, C3.1, C4.1, P1.6, U1.2 (SEL), U1.5 (VDD), U2.5 (VDD)
WS: R3.2, U1.1 (WS), U2.1 (WS)

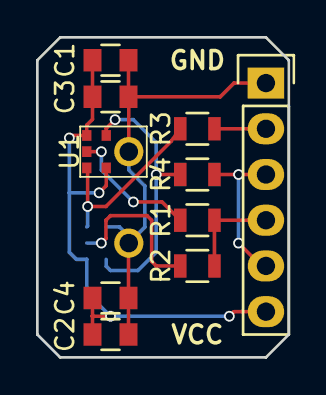
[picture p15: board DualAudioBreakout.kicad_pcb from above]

Board: 2 copper layers, 14.0 x 17.8 mm, 11 parts (1 on the bottom side), 9 nets.

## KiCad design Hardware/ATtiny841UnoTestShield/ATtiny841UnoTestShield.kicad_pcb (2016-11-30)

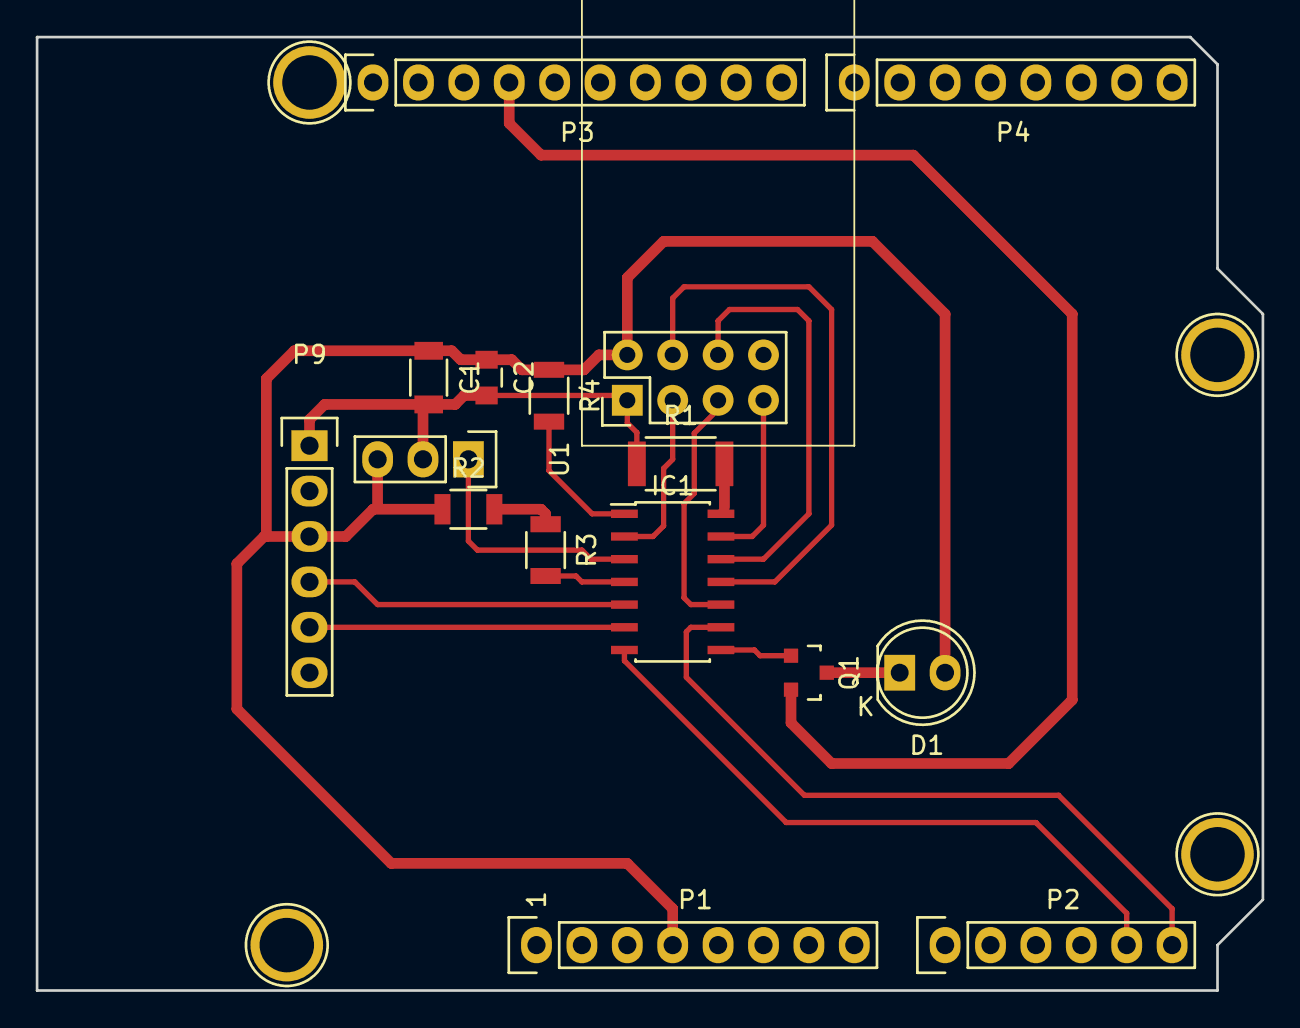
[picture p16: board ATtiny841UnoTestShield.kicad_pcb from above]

Board: 2 copper layers, 68.6 x 53.3 mm, 20 parts (0 on the bottom side), 16 nets.

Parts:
C1: 10uF; C_1206
C2: 0.1uF; C_0805
D1: LED; LED-5MM
IC1: ATTINY841-SSU; SOIC-14-N-80
P1: Power; Socket_Strip_Arduino_1x08
P2: Analog; Socket_Strip_Arduino_1x06
P3: Digital; Socket_Strip_Arduino_1x10
P4: Digital; Socket_Strip_Arduino_1x08
P5, P6, P7, P8: CONN_01X01; Arduino_1pin
P9: FTDI; Pin_Header_Straight_1x06
Q1: BSS138; SOT-23
R1: 0; R_2010
R2, R4: 0; R_1206
R3: 10K; R_1206
U1: VS18388; Pin_Header_Straight_1x03
U2: NRF24L01+

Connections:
CE: IC1.2, U2.3
GND: C1.2, C2.2, IC1.14, P1.6, P1.7, P3.4, P9.1, Q1.2, R1.1, R1.2, U1.2, U2.1
IRINPUT: IC1.3, U1.1
IRLED: IC1.8, Q1.1
MISO_ALT: IC1.13, U2.7
MOSI_ALT: IC1.12, U2.6
unnamed: D1.1, Q1.3
unnamed: IC1.4, R3.2
unnamed: R2.2, R3.1
RXI: IC1.6, P9.5
SCK_ALT: IC1.10, U2.5
SCL: IC1.9, P2.6, P3.1
SDA: IC1.7, P2.5, P3.2
SS_ALT: IC1.11, U2.4
TXO: IC1.5, P9.4
V33: C1.1, C2.1, D1.2, IC1.1, P1.4, P9.3, R2.1, R4.1, R4.2, U1.3, U2.2

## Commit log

2016-10-16 added all prexisting files to repo
    [Jotter_RevA-Parts.xlsx, Jotter_RevA.kicad_pcb, Jotter_RevA.sch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]
2016-10-17 added notes on which parts to select for development; added rought shematic and layout with most selected parts on the 3in by 3in layout to get a sense of component sizes.
    [Jotter_RevC.kicad_pcb, Jotter_RevC.sch]
2016-11-30 added hardware design for 841 uno shield with ir and ble
    [ATtiny841UnoTestShield.kicad_pcb, ATtiny841UnoTestShield.sch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]
2017-05-10 added IR transciever circuit for IR testing
    [ATtiny85UnoShield555_RevA.kicad_pcb, ATtiny85UnoShield555_RevA.sch, Attiny85IR555_RevA.kicad_pcb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]
